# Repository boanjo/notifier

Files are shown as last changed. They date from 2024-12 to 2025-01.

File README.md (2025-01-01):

# notifier
A visual alarm (led) controller over MQTT - Let the kids know it's dinner, or time to walk the dog in a non intrusive manner without shouting. Less frustration for You and no risk of interfering any streaming... 

## Background
When moving to a bigger house i quickly realized it wasn't as easy to communicate between the floor anymore, especially when headphones are on and gaming. My first solution was to use and automation with homeassistant and blinking the kids Philips hue lights. Even if it has worked fairly well for a year or two it has made the HUE lights to give up on me a number of times and i wanted something with more control over. The ZigBee and Wifi bulbs don't like flashing in my experience... My solution is to hook up a wemos D1 mini lite (Simple and cheap esp8266 chip) to my existing MQTT GW and let it control a few light modes (like flashing, worm,...) for a Adafruit Neopixel 12 LED ring. Case models and STL files are included to be 3D printed, shaped as a puck with mounting of the ESP chip and neopixel.

Notifier <br><br>

Here is an overview of my setup with many different triggers of the visual alarm (down in the left corner)

My setup

## Models
In the Fusion 360 folder you have the full assembly if you want to do your own modifications or simple print files from the STL directory.<br>

Fusion 360 Model

## BOM
Total cost should be around $30 - a bit depending on where You live
1. Wemos D1 mini lite (3.0.0) [Amazon](https://www.amazon.se/AZDelivery-ESP8266EX-WLAN-modul-kompatibel-inklusive/dp/B08BTRPMV1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) Or if you are in Sweden [Kjell&Co](https://www.kjell.com/se/produkter/el-verktyg/elektronik/utvecklingskit/arduino/utvecklingskort/luxorparts-wemos-d1-mini-utvecklingskort-p87294)
2. Adafruit Neopixel 12 LED ring [Adafruit](https://www.adafruit.com/product/1643) Or if you are in Sweden [Electrokit ](https://www.electrokit.com/neopixel-ring-12-rgb-leds-37mm)
3. M3 (3pcs) threaded inserts (for the USB cable clamp and neopixel mounting)
4. M3 (3pcs) screws
5. M2 (2pcs) threaded inserts (for the wemos board)
6. M2 (2ocs) screws
7. 1000uF electrolytic capacitor
8. USB cable + charger with 1A capacity

## How Build
For more detailed instructions, please refer to the [build instructions README.md](https://github.com/boanjo/notifier/blob/main/build_instructions/README.md) file.

HomeAssistant dashboard

## Control 
Of course you can build your own button or controller to push the commands to the MQTT GW but i'm using HomeAssistant. 
* Install and get familiar with HomeAssistant
* Install the MQTT extension (or use existing MQTT GW) - Me personally have a separate Mosquitto MQTT GW running in a docker container 
* Add an automation "+ Create Automation"
* In my case i have both a MQTT trigger from physical buttons but also from the dashboard virtual buttons above (my example)
```
topic: emil_food/cmd
payload: {"mode": "flash", "seconds": 10, "red": 0, "green": 255, "blue": 0, "req_id": 0}
```
Automation

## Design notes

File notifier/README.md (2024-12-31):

# Firmware
The firmware is pretty simple and can be extended or changed as you like:
* Connect to WiFi
* Connect to MQTT Gateway
* Listen for incoming commands
* Periodically report status and acknowledge commands

## Prerequisite
To be able to use the source code straight up, I really recommend installing PlatformIO in VSCode. Download and install VSCode, then search for and install PlatformIO. Of course, you can copy and paste the content from the `src` and `include` folders into the Arduino IDE too.

## Code updates needed
All code You need is to change are a few lines in the include/details.h file. 
* Wifi credentials - goes without saying. 
* Add the IP address of your MQTT gateway (maybe the same as your homeassistant).  
* Select a basetopic i.e. the topic that is what you send over your MQTT bus. It can be a logical name with underscore like 'basement' or 'food_alert' etc.
* Then remove the "define ERROR" since it's only there to ensure you just don't donwload and build without changing this personal stuff 

## API
There is little or no error handling for the API to not add more code than recessary so provide the json attributes as below and you should be fine:

### mode
* on - All LEDs on
* all LEDs off
* worm - the LEDs in the ring will move in a worm like circle
* flash - Flashing the LEDs

### seconds
* Number of seconds to repeat the mode range 1 to 4294967 (like 49 days)

### red
* The RGB R value 0-255

### green
* The RGB G value 0-255

### blue
* The RGB B value 0-255

### req_id
* Id to be returned in ack message (i.e. if you want to verify and keep track of which command is acknowledged)

## Example
Flash green light for 10 seconds for the topic/device oliver_food (note it's ok to have multiple devices listeing to the same topic)
```
oliver_food/cmd {'mode'='flash','seconds'=10,'red'=0,'green'=255,'blue'=0,'req_id'=0}
```

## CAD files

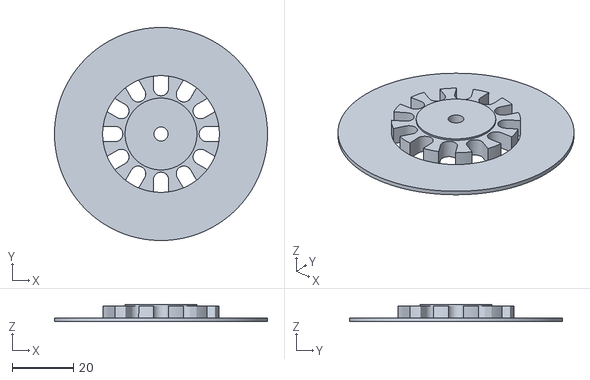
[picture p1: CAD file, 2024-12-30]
stl/neopixel mounting plate.stl
69.4 x 69.4 x 5.70

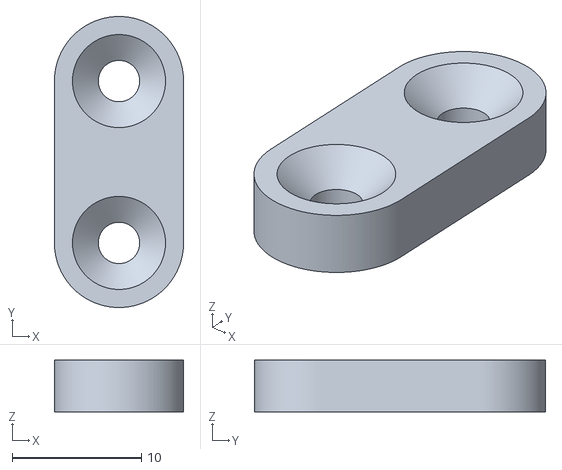
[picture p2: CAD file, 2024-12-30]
stl/bracket cable.stl
10.0 x 22.5 x 4.00

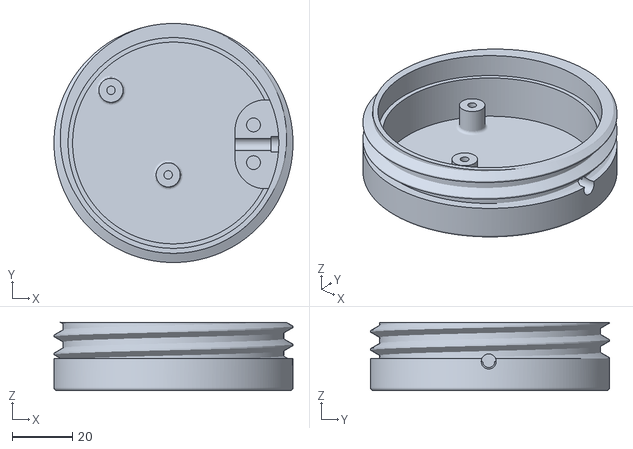
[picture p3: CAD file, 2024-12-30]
stl/notifier base.stl
79.4 x 79.4 x 22.7

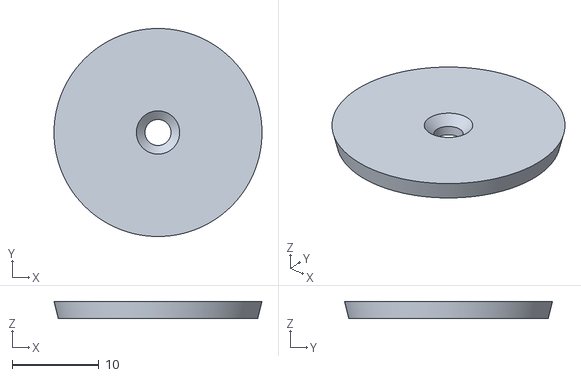
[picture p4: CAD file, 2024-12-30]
stl/bracket top.stl
24.0 x 24.0 x 2.00

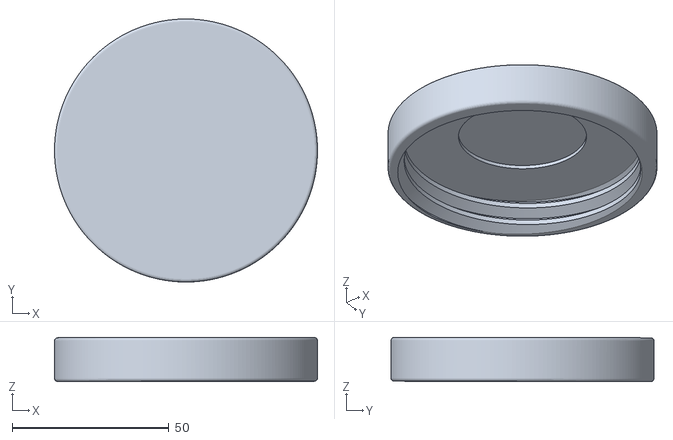
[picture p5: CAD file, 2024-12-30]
stl/notifier lid.stl
84.0 x 84.0 x 14.2

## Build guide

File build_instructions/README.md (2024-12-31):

# Build instructions
Ok, maybe a bit too detailed but here it goes - everyone with a 3D printer and a soldering iron should be able to do this in a few hours. 2h on BambuLab Carbon X1 printer and half an our of soldering

## 3D print
Best result is with some matte PLA (or whatever you like) - I used BambuLab matte white PLA. Support is not really needed
Print!

## Melt inserts
Heat up you soldering iron and melt down the 2xM2 and 3xM3 inserts
Inserts

Inserts 2

## Program the wemos D1 mini lite
For more detailed instructions, please refer to the [notifier firmware README.md](https://github.com/boanjo/notifier/blob/main/notifier/README.md) file.

## Mount and solder
Mounting

Mounting

Mounting

Mounting

Mounting

Mounting

Mounting

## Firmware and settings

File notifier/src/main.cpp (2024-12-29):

#include <Arduino.h>
#include <ESP8266WiFi.h>
#include <PubSubClient.h>
#include <Adafruit_NeoPixel.h>
#include <ArduinoJson.h>
#include "details.h"

// actual topic dynamically added in setup below 
// NOTE don't forgt to upate the details.h file
char mqtt_cmd_topic[50];  // Adjust size as needed
char mqtt_status_topic[50];  // Adjust size as needed
char client_id[100];

// NeoPixel setup
#define PIN D2 // Data pin for NeoPixel
#define NUMPIXELS 12 // Number of LEDs in the NeoPixel ring
Adafruit_NeoPixel pixels(NUMPIXELS, PIN, NEO_GRB + NEO_KHZ800);

// Globals for managing state
unsigned long lastPeriodicTime = 0;
unsigned long periodicInterval = 15 * 60 * 1000; // 15 minutes periodic reporting for wifi experience
unsigned long modeStartTime = 0;
unsigned long modeDuration = 0;

int reconnection_count = 0;
int status_count = 0;
int req_id = 0;
String current_command = "none";

bool isModeActive = false;
String activeMode = "";

// Color variables
int red = 255, green = 255, blue = 255; // Default to white

// WiFi and MQTT clients
WiFiClient espClient;
PubSubClient client(espClient);


//****************************************************************************  
// Function to connect to Wifi
//**************************************************************************** 
void setup_wifi() {
  delay(10);
  Serial.println("Connecting to WiFi...");
  WiFi.begin(ssid, password);
  while (WiFi.status() != WL_CONNECTED) {
    delay(1000);
    Serial.print(".");
  }
  Serial.println("\nWiFi connected.");
}

//**************************************************************************** 
// Function to reconnect MQTT
//**************************************************************************** 
void reconnect() {
  if (WiFi.status() != WL_CONNECTED) {
    setup_wifi(); // Reconnect Wi-Fi if disconnected
  }

  while (!client.connected()) {
    reconnection_count++; // Increment reconnection count
    Serial.print("Connecting to MQTT...");
    Serial.println(client_id);
    if (client.connect(client_id)) {
      Serial.println("Connected to MQTT.");
      client.subscribe(mqtt_cmd_topic);
    } else {
      Serial.print("Failed, rc=");
      Serial.print(client.state());
      Serial.println(" try again in 5 seconds");
      delay(5000);
    }
  }
}

//****************************************************************************  
// Function to publish status
//**************************************************************************** 
void publishStatus(const char* status_type, int req_id) {
  int rssi = WiFi.RSSI(); // Get RSSI

  JsonDocument statusDoc;
  statusDoc["status_type"] = status_type;
  statusDoc["rssi"] = rssi;
  statusDoc["reconnection_count"] = reconnection_count;
  statusDoc["req_id"] = req_id;
  statusDoc["current_command"] = current_command;

  char statusMessage[256];
  serializeJson(statusDoc, statusMessage);
  client.publish(mqtt_status_topic, statusMessage);

  Serial.print("Published status: ");
  Serial.println(statusMessage);
}

//**************************************************************************** 
// Function to handle blink modes
//**************************************************************************** 
void handleMode(String mode) {
  if (mode == "on") {
    for (int i = 0; i < NUMPIXELS; i++) {
      pixels.setPixelColor(i, pixels.Color(red, green, blue)); // Set color
    }
    pixels.show();
  } else if (mode == "off") {
    pixels.clear();
    pixels.show();
  } else if (mode == "worm") {
    int position = (millis() / 100) % NUMPIXELS;
    pixels.clear();
    pixels.setPixelColor(position, pixels.Color(red, green, blue)); // Worm color
    pixels.show();
  } else if (mode == "flash") {
    int state = (millis() / 500) % 2; // Toggle every 500ms
    for (int i = 0; i < NUMPIXELS; i++) {
      pixels.setPixelColor(i, state == 0 ? pixels.Color(red, green, blue) : pixels.Color(0, 0, 0)); // Flash color
    }
    pixels.show();
  }
}

//**************************************************************************** 
// callback - Function to handle incoming MQTT messages
//**************************************************************************** 
void callback(char* topic, byte* payload, unsigned int length) {

  // Parse incoming message
  char message[length + 1];
  memcpy(message, payload, length);
  message[length] = '\0';
  Serial.print("Message received: ");
  Serial.println(message);

  JsonDocument doc;
  DeserializationError error = deserializeJson(doc, message);

  if (error) {
    Serial.print("JSON parse error: ");
    Serial.println(error.c_str());
    return;
  }

  // Extract parameters
  const char* mode = doc["mode"];
  int seconds = doc["seconds"];
  req_id = doc["req_id"];
  red = doc["red"];
  green = doc["green"];
  blue = doc["blue"];

  // Update state
  activeMode = String(mode);
  current_command = activeMode;
  modeStartTime = millis();
  modeDuration = seconds * 1000;
  isModeActive = true;

  // Publish acknowledgment
  publishStatus("acknowledged", req_id);
}

//**************************************************************************** 
// handlePeriodicReporting - Function to handle periodic reporting
//**************************************************************************** 
void handlePeriodicReporting() {
  unsigned long currentTime = millis();
  if (currentTime - lastPeriodicTime >= periodicInterval) {
    lastPeriodicTime = currentTime;
    publishStatus("periodic", status_count);
      status_count++; // Increment request count

  }
}

//**************************************************************************** 
// setup
//**************************************************************************** 
void setup() {
  Serial.begin(115200);
  setup_wifi();

  // Use Wifi MAC for client id uniqueness
  String mac = WiFi.macAddress();
  mac.replace(":", "");  // Remove colons
  snprintf(client_id, sizeof(client_id), "%s_%s", base_topic, mac.c_str());

  snprintf(mqtt_cmd_topic, sizeof(mqtt_cmd_topic), "%s/cmd", base_topic);
  snprintf(mqtt_status_topic, sizeof(mqtt_status_topic), "%s/status", base_topic);

  client.setServer(mqtt_server, 1883);
  client.setCallback(callback);

  pixels.begin();
  pixels.clear();
}


//**************************************************************************** 
// loop
//**************************************************************************** 
void loop() {
  if (!client.connected()) {
    reconnect();
  }
  client.loop();

  // Handle active mode
  if (isModeActive) {
    handleMode(activeMode);

    if (millis() - modeStartTime >= modeDuration) {
      isModeActive = false;
      activeMode = "off";
      handleMode("off");
      current_command = "none";
      publishStatus("completed", req_id);
    }
  }

  // Handle periodic reporting
  handlePeriodicReporting();
}
